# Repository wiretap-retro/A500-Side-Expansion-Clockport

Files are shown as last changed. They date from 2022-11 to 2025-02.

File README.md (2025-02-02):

# A500 Side Expansion Clockport
A simple clockport adapter for the A500 side expansion slot.

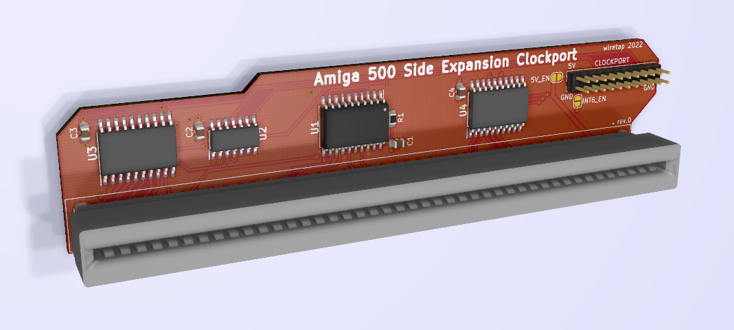
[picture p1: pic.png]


## Info
Designed for my Amiga 500 tower. Might fit inside a the factory A500 case. Functionally tested by Fletch with an A314cp. Will not work with a A1200 RTC since the appropriate clock signals aren't present on the A500 side expansion bus. Please solder bridge INT6_EN, unless you have a specific use case where it is not necessary.

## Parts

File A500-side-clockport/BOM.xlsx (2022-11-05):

Reference | Value | Footprint | Description | Manufacturer Name | Manufacturer Part Number
BUS0 | A500_SLOT | SamacSys_Parts:TE_1-5530843-0 | Amiga 500 side expansion slot edge connector | TE Connectivity | 1-5530843-0
C1 | 100nF | Capacitor_SMD:C_0805_2012Metric_Pad1.15x1.40mm_HandSolder | 0805 Capacitor
C2 | 100nF | Capacitor_SMD:C_0805_2012Metric_Pad1.15x1.40mm_HandSolder | 0805 Capacitor
C3 | 100nF | Capacitor_SMD:C_0805_2012Metric_Pad1.15x1.40mm_HandSolder | 0805 Capacitor
C4 | 100nF | Capacitor_SMD:C_0805_2012Metric_Pad1.15x1.40mm_HandSolder | 0805 Capacitor
J0 | CLOCKPORT | Connector_PinHeader_2.00mm:PinHeader_2x11_P2.00mm_Vertical | 2x11 2.0mm Pitch Pin Header
J1 | 5V_EN | Jumper:SolderJumper-2_P1.3mm_Open_RoundedPad1.0x1.5mm | Solder jumper
J2 | INT6_EN | Jumper:SolderJumper-2_P1.3mm_Open_RoundedPad1.0x1.5mm | Solder jumper
R1 | 4.7k | Resistor_SMD:R_0805_2012Metric_Pad1.15x1.40mm_HandSolder | 0805 Resistor
U1 | 74HCT688 | Package_SO:SOIC-20W_7.5x12.8mm_P1.27mm | 8-bit Identity Comparator | Texas Instruments | SN74HCT688DW
U2 | SN74AC00D | SamacSys_Parts:SOIC127P600X175-14N | Quadruple 2-Input Positive-NAND Gates | Texas Instruments | SN74AC00D
U3 | SN74AC245DW | SamacSys_Parts:SOIC127P1030X265-20N | Texas Instruments SN74AC245DW, Bus Transceiver, 8-Bit Non-Inverting CMOS, 2 6 V, 20-Pin SOIC | Texas Instruments | SN74AC245DW
U4 | SN74AC245DW | SamacSys_Parts:SOIC127P1030X265-20N | Texas Instruments SN74AC245DW, Bus Transceiver, 8-Bit Non-Inverting CMOS, 2 6 V, 20-Pin SOIC | Texas Instruments | SN74AC245DW

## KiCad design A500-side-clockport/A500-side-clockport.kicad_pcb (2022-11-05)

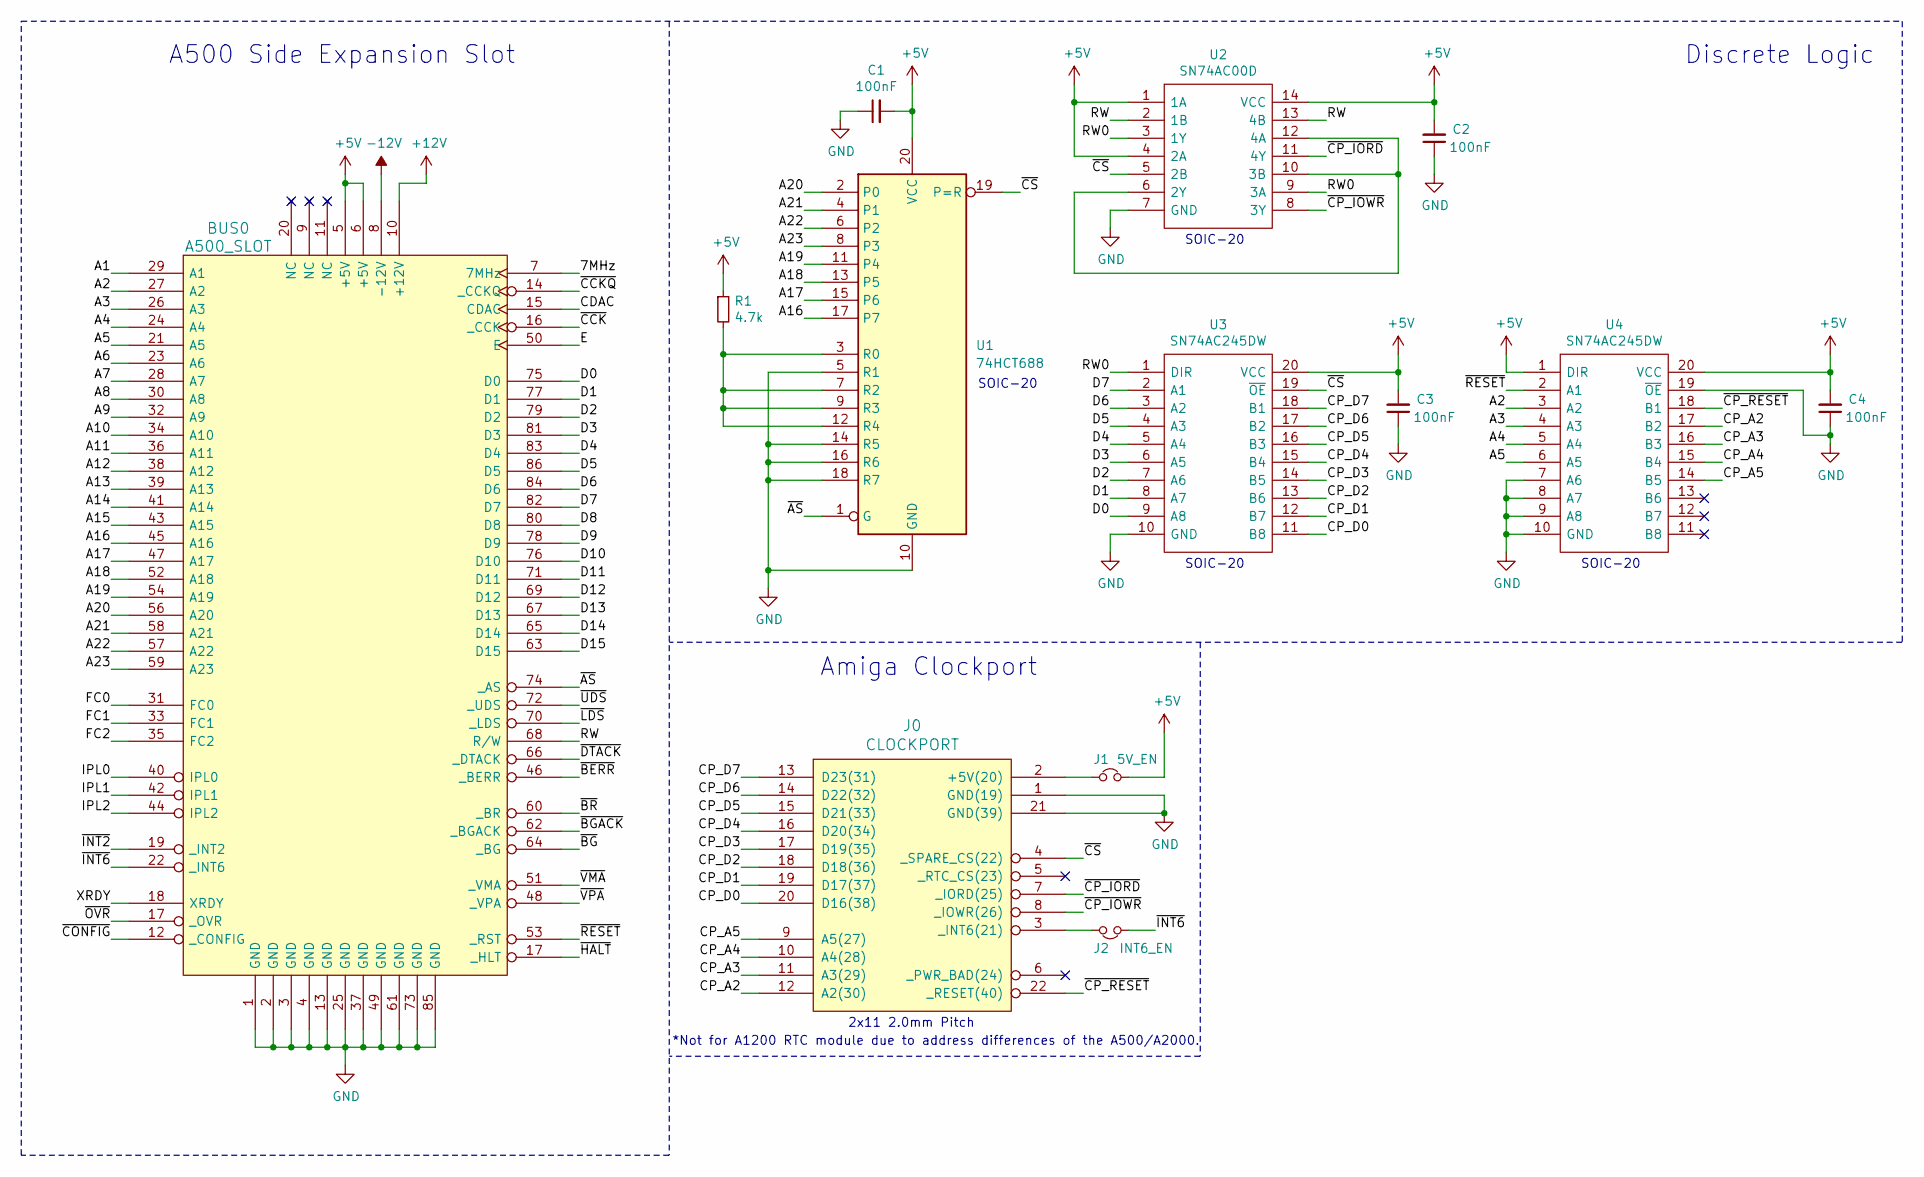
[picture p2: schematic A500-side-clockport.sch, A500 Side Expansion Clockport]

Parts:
BUS0: A500_SLOT; TE_1-5530843-0
C1, C2, C3, C4: 100nF; C_0805_2012Metric_Pad1.15x1.40mm_HandSolder
J0: CLOCKPORT; PinHeader_2x11_P2.00mm_Vertical
J1: 5V_EN; SolderJumper-2_P1.3mm_Open_RoundedPad1.0x1.5mm
J2: INT6_EN; SolderJumper-2_P1.3mm_Open_RoundedPad1.0x1.5mm
R1: 4.7k; R_0805_2012Metric_Pad1.15x1.40mm_HandSolder
U1: 74HCT688; SOIC-20W_7.5x12.8mm_P1.27mm
U2: SN74AC00D; SOIC127P600X175-14N; Mouser Part Number 595-SN74AC00D
U3, U4: SN74AC245DW; SOIC127P1030X265-20N; Mouser Part Number 595-SN74AC245DW

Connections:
+5V: BUS0.5 (+5V), BUS0.6 (+5V), C1.2, C2.2, C3.2, C4.2, J1.2, R1.1, U1.20 (VCC), U2.1 (1A), U2.4 (2A), U2.14 (VCC), U3.20 (VCC), U4.1 (DIR), U4.20 (VCC)
+12V: BUS0.10 (+12V)
-12V: BUS0.8 (-12V)
/7MHz: BUS0.7 (7MHz)
/A1: BUS0.29 (A1)
/A2: BUS0.27 (A2), U4.3 (A2)
/A3: BUS0.26 (A3), U4.4 (A3)
/A4: BUS0.24 (A4), U4.5 (A4)
/A5: BUS0.21 (A5), U4.6 (A5)
/A6: BUS0.23 (A6)
/A7: BUS0.28 (A7)
/A8: BUS0.30 (A8)
/A9: BUS0.32 (A9)
/A10: BUS0.34 (A10)
/A11: BUS0.36 (A11)
/A12: BUS0.38 (A12)
/A13: BUS0.39 (A13)
/A14: BUS0.41 (A14)
/A15: BUS0.43 (A15)
/A16: BUS0.45 (A16), U1.17 (P7)
/A17: BUS0.47 (A17), U1.15 (P6)
/A18: BUS0.52 (A18), U1.13 (P5)
/A19: BUS0.54 (A19), U1.11 (P4)
/A20: BUS0.56 (A20), U1.2 (P0)
/A21: BUS0.58 (A21), U1.4 (P1)
/A22: BUS0.57 (A22), U1.6 (P2)
/A23: BUS0.59 (A23), U1.8 (P3)
/CDAC: BUS0.15 (CDAC)
/CP_A2: J0.12 (A2(30)), U4.17 (B2)
/CP_A3: J0.11 (A3(29)), U4.16 (B3)
/CP_A4: J0.10 (A4(28)), U4.15 (B4)
/CP_A5: J0.9 (A5(27)), U4.14 (B5)
/CP_D0: J0.20 (D16(38)), U3.11 (B8)
/CP_D1: J0.19 (D17(37)), U3.12 (B7)
/CP_D2: J0.18 (D18(36)), U3.13 (B6)
/CP_D3: J0.17 (D19(35)), U3.14 (B5)
/CP_D4: J0.16 (D20(34)), U3.15 (B4)
/CP_D5: J0.15 (D21(33)), U3.16 (B3)
/CP_D6: J0.14 (D22(32)), U3.17 (B2)
/CP_D7: J0.13 (D23(31)), U3.18 (B1)
/D0: BUS0.75 (D0), U3.9 (A8)
/D1: BUS0.77 (D1), U3.8 (A7)
/D2: BUS0.79 (D2), U3.7 (A6)
/D3: BUS0.81 (D3), U3.6 (A5)
/D4: BUS0.83 (D4), U3.5 (A4)
/D5: BUS0.86 (D5), U3.4 (A3)
/D6: BUS0.84 (D6), U3.3 (A2)
/D7: BUS0.82 (D7), U3.2 (A1)
/D8: BUS0.80 (D8)
/D9: BUS0.78 (D9)
/D10: BUS0.76 (D10)
/D11: BUS0.71 (D11)
/D12: BUS0.69 (D12)
/D13: BUS0.67 (D13)
/D14: BUS0.65 (D14)
/D15: BUS0.63 (D15)
/E: BUS0.50 (E)
/FC0: BUS0.31 (FC0)
/FC1: BUS0.33 (FC1)
/FC2: BUS0.35 (FC2)
/IPL0: BUS0.40 (IPL0)
/IPL1: BUS0.42 (IPL1)
/IPL2: BUS0.44 (IPL2)
/RW: BUS0.68 (R/W), U2.2 (1B), U2.13 (4B)
/RW0: U2.3 (1Y), U2.9 (3A), U3.1 (DIR)
/XRDY: BUS0.18 (XRDY)
/~AS: BUS0.74 (_AS), U1.1 (G)
/~BERR: BUS0.46 (_BERR)
/~BG: BUS0.64 (_BG)
/~BGACK: BUS0.62 (_BGACK)
/~BR: BUS0.60 (_BR)
/~CCK: BUS0.16 (_CCK)
/~CCKQ: BUS0.14 (_CCKQ)
/~CONFIG: BUS0.12 (_CONFIG)
/~CP_IORD: J0.7 (_IORD(25)), U2.11 (4Y)
/~CP_IOWR: J0.8 (_IOWR(26)), U2.8 (3Y)
/~CP_RESET: J0.22 (_RESET(40)), U4.18 (B1)
/~CS: J0.4 (_SPARE_CS(22)), U1.19 (P=R), U2.5 (2B), U3.19 (~OE)
/~DTACK: BUS0.66 (_DTACK)
/~INT2: BUS0.19 (_INT2)
/~INT6: BUS0.22 (_INT6), J2.1
/~LDS: BUS0.70 (_LDS)
/~RESET: BUS0.53 (_RST), U4.2 (A1)
/~UDS: BUS0.72 (_UDS)
/~VMA: BUS0.51 (_VMA)
/~VPA: BUS0.48 (_VPA)
GND: BUS0.1 (GND), BUS0.2 (GND), BUS0.3 (GND), BUS0.4 (GND), BUS0.13 (GND), BUS0.25 (GND), BUS0.37 (GND), BUS0.49 (GND), BUS0.61 (GND), BUS0.73 (GND), BUS0.85 (GND), C1.1, C2.1, C3.1, C4.1, J0.1 (GND(19)), J0.21 (GND(39)), U1.5 (R1), U1.10 (GND), U1.14 (R5), U1.16 (R6), U1.18 (R7), U2.7 (GND), U3.10 (GND), U4.7 (A6), U4.8 (A7), U4.9 (A8), U4.10 (GND), U4.19 (~OE)
unnamed: J0.2 (+5V(20)), J1.1
unnamed: J0.3 (_INT6(21)), J2.2
unnamed: R1.2, U1.3 (R0), U1.7 (R2), U1.9 (R3), U1.12 (R4)
unnamed: U2.6 (2Y), U2.10 (3B), U2.12 (4A)

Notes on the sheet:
A500 Side Expansion Slot
Amiga Clockport
SOIC-20
2x11 2.0mm Pitch
Discrete Logic
*Not for A1200 RTC module due to address differences of the A500/A2000.

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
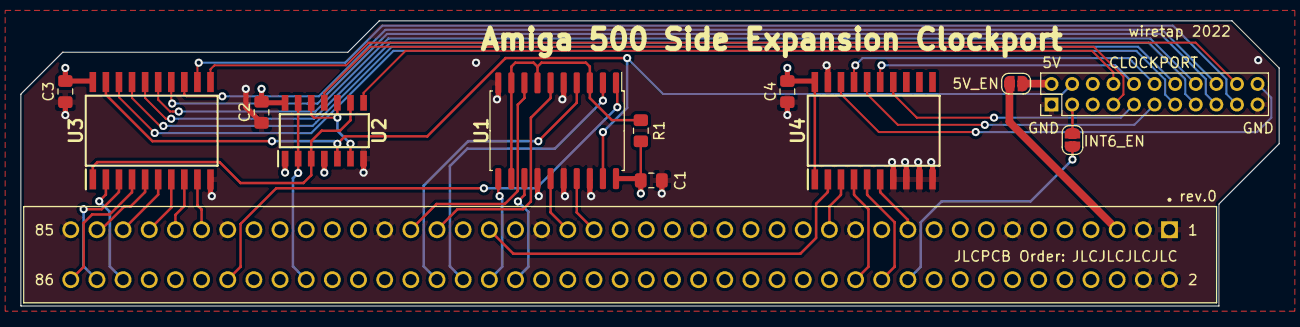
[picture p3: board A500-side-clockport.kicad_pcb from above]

Board: 4 copper layers, 122.2 x 27.7 mm, 13 parts (0 on the bottom side), 47 nets.
